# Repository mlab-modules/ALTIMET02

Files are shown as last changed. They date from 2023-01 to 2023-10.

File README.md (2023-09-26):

# ALTIMET02 - Precision Digital Pressure, temperature, and altimeter sensor

The [MLAB ALTIMET02](https://github.com/mlab-modules/ALTIMET02) is a high-performance pressure and temperature sensing module, based on the [MS561101BA03](https://www.te.com/usa-en/product-MS561101BA03-50.html) pressure sensor. This module is designed for use in a variety of applications, including meteorology, navigation, climate monitoring, and other scientific and industrial applications. 

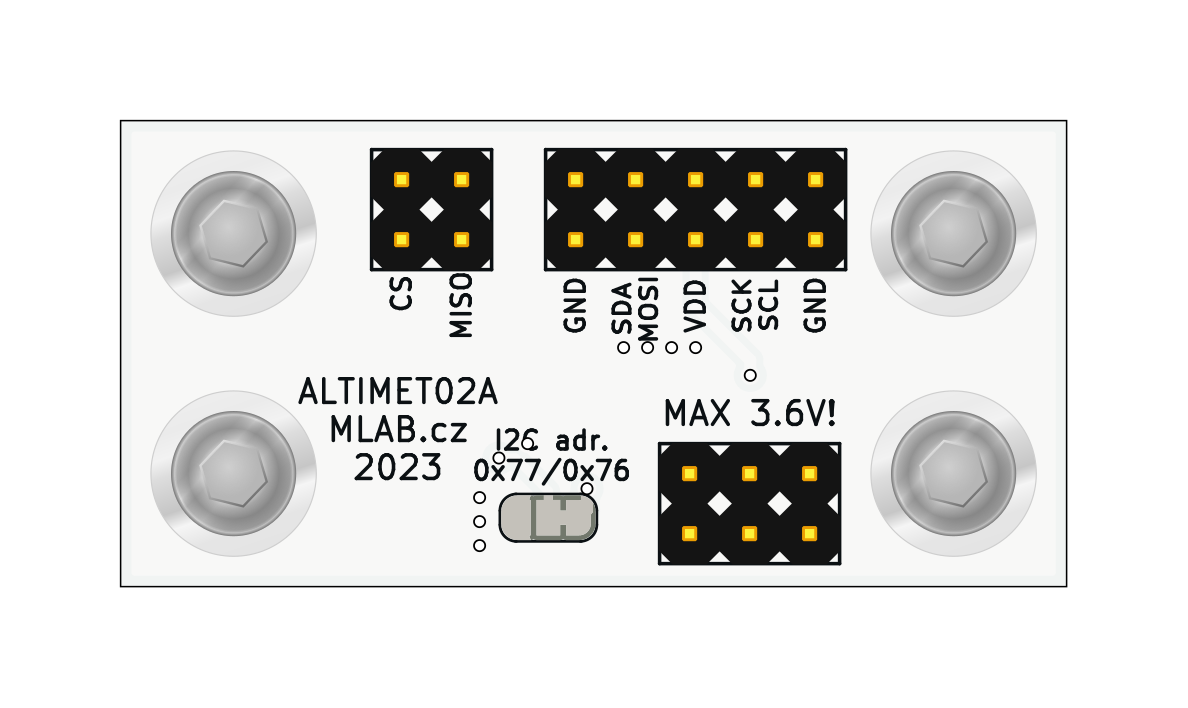
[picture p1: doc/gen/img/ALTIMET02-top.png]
ALTIMET02A top PCB
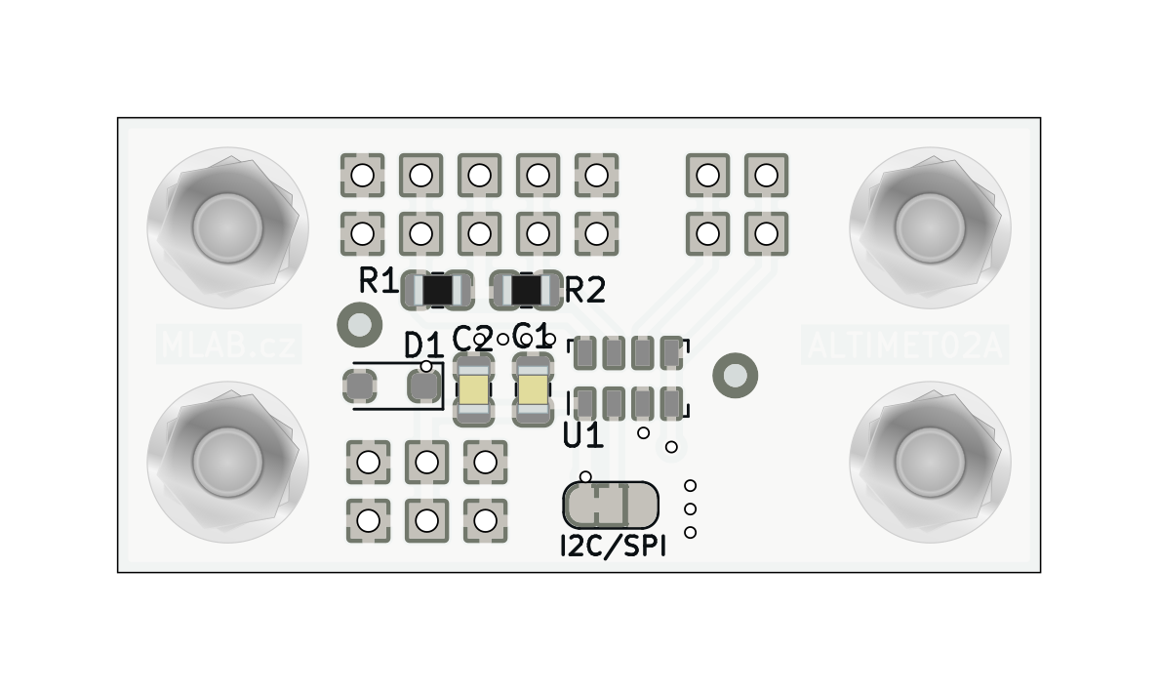
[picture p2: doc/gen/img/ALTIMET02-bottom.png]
ALTIMET02A bottom PCB
 

## Specifications

The key component of the ALTIMET02 module is TE Connectivity MS561101BA03 sensor. This sensor is a highly accurate and low-power barometric sensor with a resolution of up to 10 cm. The sensor provides a 24-bit digital output via the I2C or SPI interfaces, allowing for easy integration with various microcontrollers.

ALTIMET02 Module Schematic

### Parameters

* Pressure and Temperature measurement
* Pressure resolution: 10 cm
* Temperature resolution: 0.01°C
* Communication interface: I2C and SPI
* Supply voltage: 1.8V to 3.6V
* Power consumption: Low (<1uA during measurement)
* Full-scale pressure range: 10 - 1200 mbar
* Operating temperature range: -40 to +85 °C
* High reliability and long-term stability
* Advanced error compensation
* Enhanced EMI Protection

## Use Cases

The ALTIMET02 module is primarily designed as a pressure-sensing device for scientific experiments like statospheric balloons, but its capabilities extend far beyond this purpose. With high accuracy and low power consumption, the module is ideal for a wide range of applications.

### Atmospheric pressure and meteorological applications

As an atmospheric pressure sensor, ALTIMET02 is extremely suitable for meteorological applications. The module can be used for tracking pressure changes over time, which can provide valuable data for weather prediction. The combination of pressure and temperature measurements can help create a more detailed picture of atmospheric conditions.

### Altimetry and navigation

Altitude measurement is another key area where ALTIMET02 excels. Altitude measurement can be done using the barometric method, which uses the change in atmospheric pressure with altitude. This is useful for various types of navigation, including hiking, aviation, and marine navigation.

### Climate monitoring and scientific applications

ALTIMET02 is also a tool for scientific and industrial applications where it is important to monitor changes in climatic conditions. The module can be, for example, used in the field of scientific research to study climate change or in industry for monitoring and controlling conditions in various environments, such as greenhouses, warehouses, and production halls.

### Low power consumption applications

Due to its low power consumption, ALTIMET02 is suitable for applications that require long-term monitoring without frequent charging or battery replacement. This can include remote weather stations, animal trackers, or other portable devices.

## Connection to Microcontroller

The ALTIMET02 module can be easily connected to a microcontroller via the I2C or SPI interfaces.

For connecting the module to a microcontroller via the I2C interface, it is necessary to connect SDA (data line) and SCL (clock line) to the corresponding pins on the microcontroller.

For connection via the SPI interface, it is necessary to connect CSB (chip select), SDO (serial data output), SDI (serial data input), and SCLK (serial clock) to the corresponding pins on the microcontroller.

## Conclusion

The ALTIMET02 module is a highly accurate and low-power pressure and temperature

 sensing module, ideal for various applications. Its simple interface and small size allow for easy integration into any project. Its wide range of uses makes it an ideal solution for many different applications. For further information, please refer to the [ALTIMET02](https://github.com/mlab-modules/ALTIMET02) and the [MLAB website](https://www.mlab.cz/).

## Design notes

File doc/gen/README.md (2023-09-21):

# PCB

Board size: 40.13x19.81 mm (1.58x0.78 inches)

- This is the size of the rectangle that contains the board
- Thickness: 1.6 mm (63 mils)
- Material: FR4
- Finish: None
- Layers: 2
- Copper thickness: 35 µm

Solder mask: TOP / BOTTOM

- Color: Green

Silk screen: TOP / BOTTOM

- Color: White

Stackup:

| Name | Type | Color | Thickness | Material | Epsilon_r | Loss tangent |
|---|---|---|---|---|---|---|
| F.SilkS | Top Silk Screen | | | | | |
| F.Paste | Top Solder Paste | | | | | |
| F.Mask | Top Solder Mask | | 10 | | | |
| F.Cu | copper | | 35 | | | |
| dielectric 1 | core | | 1510 | FR4 | 4.5 | 0.020 |
| B.Cu | copper | | 35 | | | |
| B.Mask | Bottom Solder Mask | | 10 | | | |
| B.Paste | Bottom Solder Paste  | | | | | |
| B.SilkS | Bottom Silk Screen | | | | | |

# Important sizes

Clearance: 0.2 mm (8 mils)

Track width: 0.25 mm (10 mils)

- By design rules: 0.0 mm (0 mils)

Drill: 0.5 mm (20 mils)

- Vias: 0.5 mm (20 mils) [Design: 0.4 mm (16 mils)]
- Pads: 1.0 mm (39 mils)
- The above values are real drill sizes, they add 0.1 mm (4 mils) to plated holes (PTH)

Via: 0.8/0.4 mm (31/16 mils)

- By design rules: 0.5/0.3 mm (20/12 mils)
- Micro via: yes [0.2/0.1 mm (8/4 mils)]
- Buried/blind via: yes
- Total: 11 (thru: 11 buried/blind: 0 micro: 0)

Outer Annular Ring: 0.15 mm (6 mils)

- By design rules: 0.26 mm (10 mils)

Eurocircuits class: 4B
- Using min drill 0.5 mm for an OAR of 0.15 mm

# General stats

Components count: (SMD/THT)

- Top: 0/7 (THT)
- Bottom: 8/0 (SMD)

Defined tracks:

Used tracks:

- 0.25 mm (10 mils) (2) defined: no
- 0.38 mm (15 mils) (19) defined: no
- 0.4 mm (16 mils) (10) defined: no
- 0.51 mm (20 mils) (25) defined: no

Defined vias:

Used vias:

- 0.8/0.4 mm (31/16 mils) (Count: 11, Aspect: 2.0 A) defined: no

Holes (excluding vias):

- 0.89 mm (35 mils) (20)
- 3.0 mm (118 mils) (4)

Oval holes:

Drill tools (including vias and computing adjusts and rounding):

- 0.5 mm (20 mils) (11)
- 1.0 mm (39 mils) (20)
- 3.1 mm (122 mils) (4)

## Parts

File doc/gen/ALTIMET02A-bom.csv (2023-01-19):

Row | Description | Part | References | Value | Footprint | Quantity Per PCB | Status | Datasheet | Height | Mouser Part Number | Mouser Price/Stock | Manufacturer_Name | Manufacturer_Part_Number
1 | Unpolarized capacitor | C | C2 | 100nF | C_0805_2012Metric | 1 |  | ~
2 | Unpolarized capacitor | C | C1 | 10uF | C_0805_2012Metric | 1 |  | ~
3 | Zener diode | D_Zener | D1 | BZV55C3V6 | Diode-MiniMELF_Standard | 1 |  | ~
4 | Sensor Pressure 1.2bar Barometric SMD MS561101BA03-50, Barometric Pressure Sensor, 1200mbar 0 3.6 V Output, 8-Pin QFN | MS561101BA03-50 | IC1 | MS561101BA03-50 | MS561101BA03-50 | 1 |  | https://www.te.com/usa-en/product-MS561101BA03-50.datasheet.pdf |  | 824-MS561101BA03-50 | https://www.mouser.co.uk/ProductDetail/Measurement-Specialties/MS561101BA03-50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 | TE Connectivity | MS561101BA03-50
5 | 2x03 2.54 mm pitch header | HEADER_2x03 | J2 | HEADER_2x03 | Straight_2x03 | 1
6 | 2x05 2.54 mm pitch header, 2 pins next to each other are connected | HEADER_2x05_PARALLEL | J3 | HEADER_2x05_PARALLEL | Straight_2x05 | 1
Project info:
Schematic: | ALTIMET02A
Variant: | default
Revision: | A
Date: | 2023-01-18
KiCad Version: | 6.0.10+dfsg-1~bpo11+1
Statistics:
Component Groups: | 7
Component Count: | 8
Fitted Components: | 6
Number of PCBs: | 1
Total Components: | 6

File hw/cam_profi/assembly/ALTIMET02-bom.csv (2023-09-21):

Component | Description | Part | References | Value | Footprint | Quantity Per PCB | Datasheet | ust_id
1 | Unpolarized capacitor | C | C2 | 100nF | C_0805_2012Metric | 1 | ~ | 5c70984712875079b91f8b4c
2 | Unpolarized capacitor | C | C1 | 10uF | C_0805_2012Metric | 1 | ~ | 5c70984712875079b91f8b53
3 | Zener diode | D_Zener | D1 | BZT52H-C3V6,115 | D_SOD-123F | 1 | ~ | 650b35ab462c6d9e720543d0
4 | 2x02 2.54 mm pitch header, 2 pins next to each other are connected | HEADER_2x02_PARALLEL | J1 | HEADER_2x02_PARALLEL | Straight_2x02 | 1
5 | 2x03 2.54 mm pitch header, 2 pins next to each other are connected | HEADER_2x03_PARALLEL | J2 | HEADER_2x03_PARALLEL | Straight_2x03 | 1
6 | 2x05 2.54 mm pitch header, 2 pins next to each other are connected | HEADER_2x05_PARALLEL | J3 | HEADER_2x05_PARALLEL | Straight_2x05 | 1
7 | Resistor | R | R1R2 | 5k1 | R_0805_2012Metric | 2 | ~ | 5fa0fc3e12875025b3977997
8 | Barometric pressure sensor, 10cm resolution, 10 to 1200 mbar, I2C and SPI interface up to 20MHz, LGA-8 | MS5611-01BA | U1 | MS5611-01BA | MS5611-01BA03 | 1 | https://www.te.com/commerce/DocumentDelivery/DDEController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 | 650b36b0462c6d9e720543f4

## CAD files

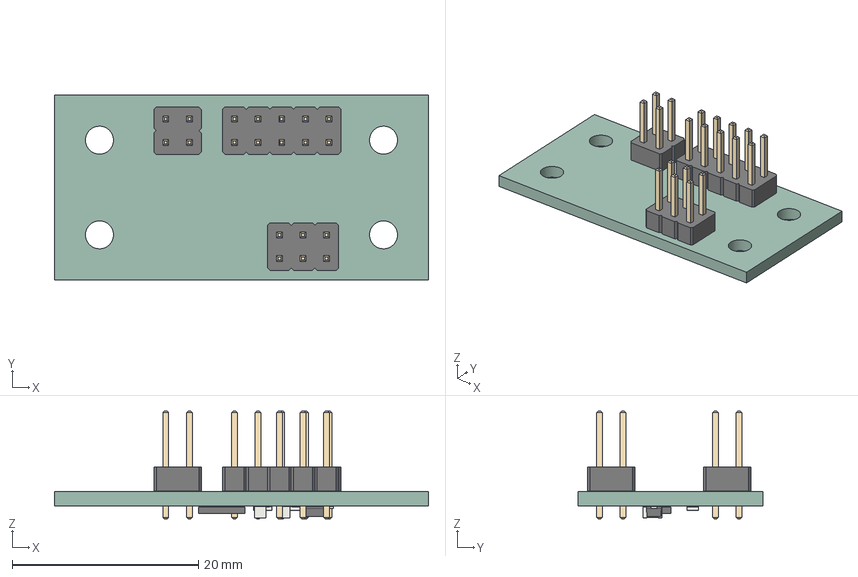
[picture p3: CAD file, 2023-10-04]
doc/gen/ALTIMET02.step
40.1 x 19.8 x 11.5 mm
tmp0cc4rao0 PCB

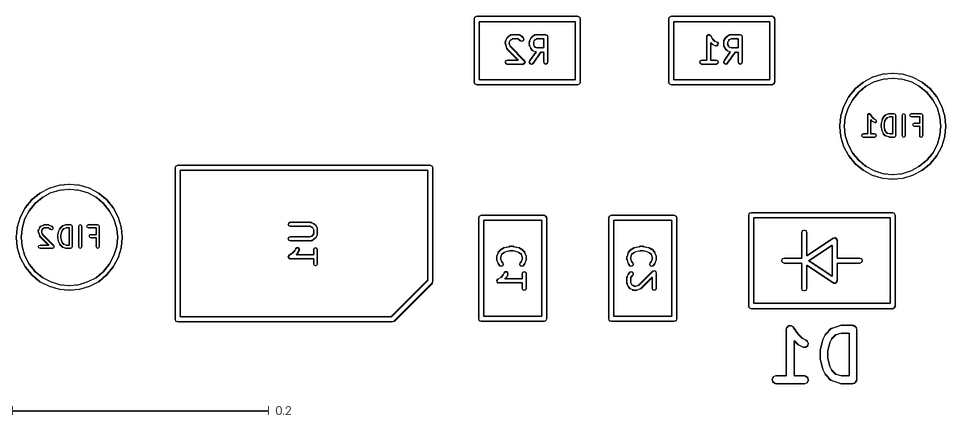
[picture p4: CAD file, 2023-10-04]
doc/gen/dxf/ALTIMET02-B_Fab.dxf
0.724 x 0.286

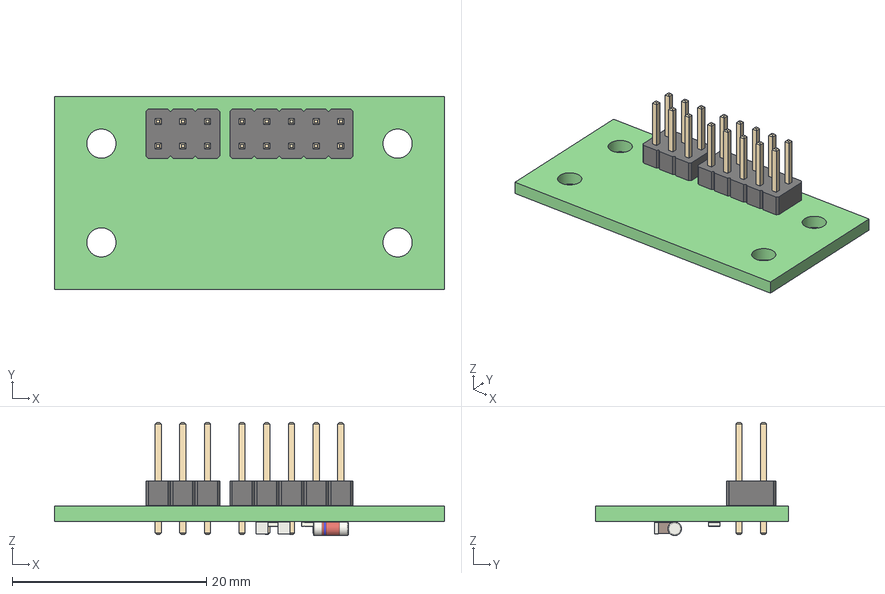
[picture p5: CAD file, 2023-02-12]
doc/gen/ALTIMET02A.step
40.1 x 19.8 x 11.6 mm
tmpe_0kkv2t PCB

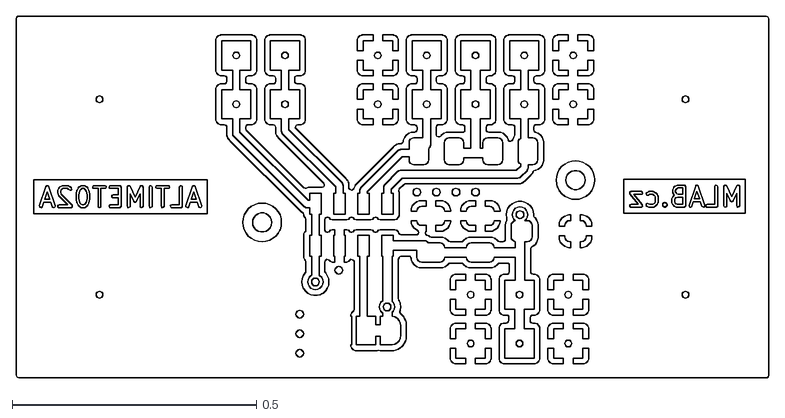
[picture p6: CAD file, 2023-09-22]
doc/gen/dxf/ALTIMET02-B_Cu.dxf
1.54 x 0.741

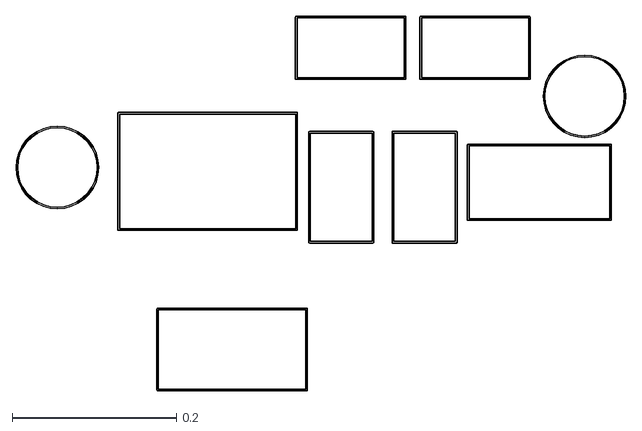
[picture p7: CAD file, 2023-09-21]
doc/gen/dxf/ALTIMET02-B_Courtyard.dxf
0.742 x 0.456

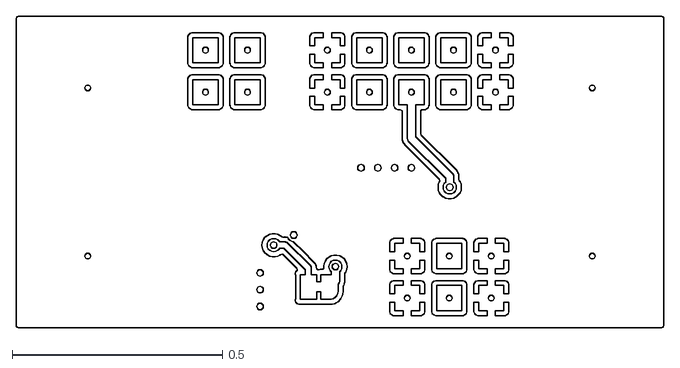
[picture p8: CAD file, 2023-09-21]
doc/gen/dxf/ALTIMET02-F_Cu.dxf
1.54 x 0.741

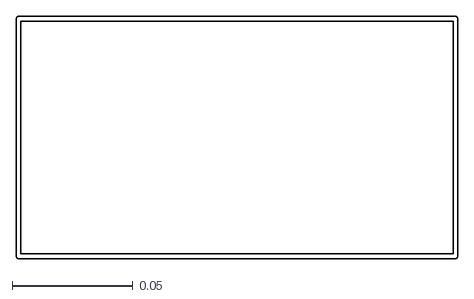
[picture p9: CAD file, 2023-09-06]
doc/gen/dxf/ALTIMET02-F_Courtyard.dxf
0.183 x 0.1

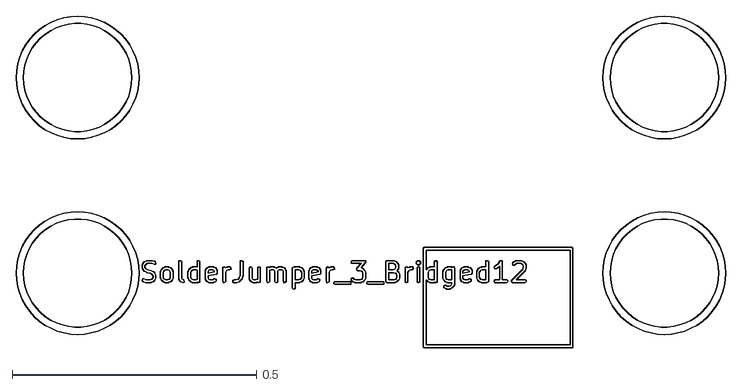
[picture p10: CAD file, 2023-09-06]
doc/gen/dxf/ALTIMET02-F_Fab.dxf
1.45 x 0.679

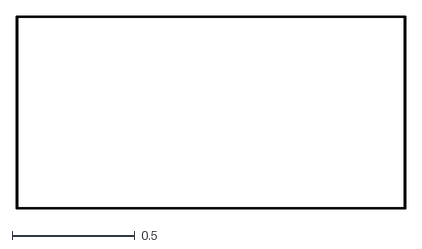
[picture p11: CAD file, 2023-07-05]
doc/gen/dxf/ALTIMET02-Edge_Cuts.dxf
1.58 x 0.785

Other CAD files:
doc/gen/dxf/ALTIMET02-User_Comments.dxf
doc/gen/dxf/ALTIMET02-User_2.dxf
doc/gen/dxf/ALTIMET02A-User_9.dxf
doc/gen/dxf/ALTIMET02A-User_3.dxf
doc/gen/dxf/ALTIMET02-User_6.dxf
doc/gen/dxf/ALTIMET02-Margin.dxf
doc/gen/dxf/ALTIMET02A-User_Drawings.dxf
doc/gen/dxf/ALTIMET02-User_8.dxf
doc/gen/dxf/ALTIMET02A-User_2.dxf
doc/gen/dxf/ALTIMET02-B_Adhesive.dxf
doc/gen/dxf/ALTIMET02-B_Mask.dxf
doc/gen/dxf/ALTIMET02-B_Paste.dxf
doc/gen/dxf/ALTIMET02-B_Silkscreen.dxf
doc/gen/dxf/ALTIMET02-F_Adhesive.dxf
doc/gen/dxf/ALTIMET02-F_Mask.dxf
doc/gen/dxf/ALTIMET02-F_Paste.dxf
doc/gen/dxf/ALTIMET02-F_Silkscreen.dxf
doc/gen/dxf/ALTIMET02-User_1.dxf
doc/gen/dxf/ALTIMET02-User_3.dxf
doc/gen/dxf/ALTIMET02-User_4.dxf
doc/gen/dxf/ALTIMET02-User_5.dxf
doc/gen/dxf/ALTIMET02-User_7.dxf
doc/gen/dxf/ALTIMET02-User_9.dxf
doc/gen/dxf/ALTIMET02-User_Drawings.dxf
doc/gen/dxf/ALTIMET02-User_Eco1.dxf
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

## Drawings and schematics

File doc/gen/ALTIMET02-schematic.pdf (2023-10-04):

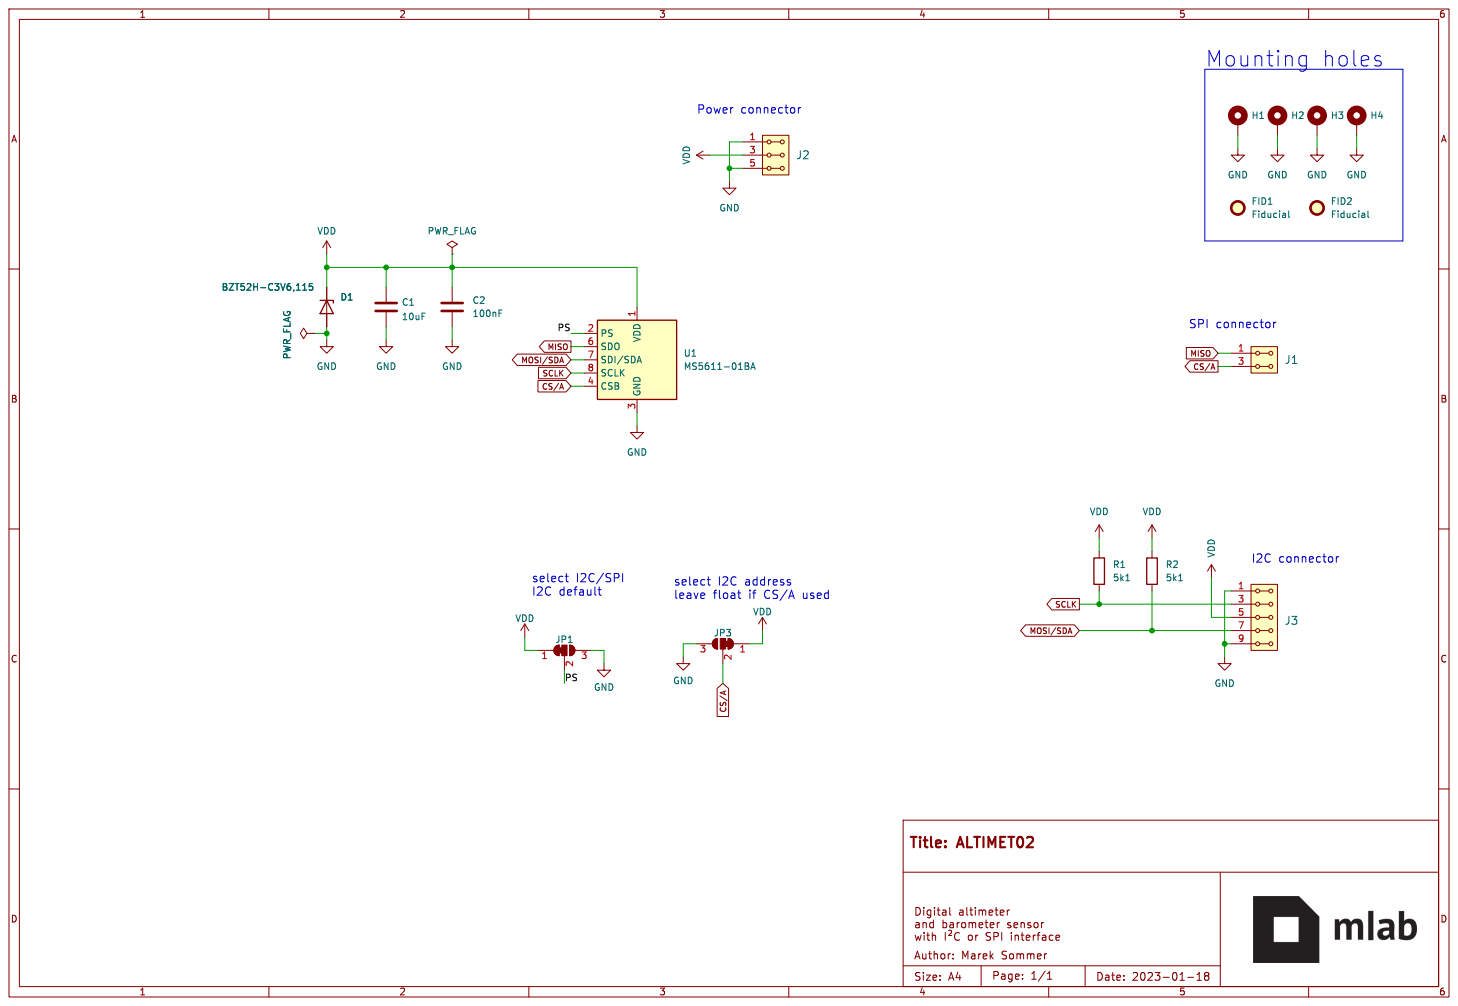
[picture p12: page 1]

3 CSB 4 SDO 6 SDI/SDA 7 SCLK 8 U1 MS5611-01BA GND

leave float if CS/A used

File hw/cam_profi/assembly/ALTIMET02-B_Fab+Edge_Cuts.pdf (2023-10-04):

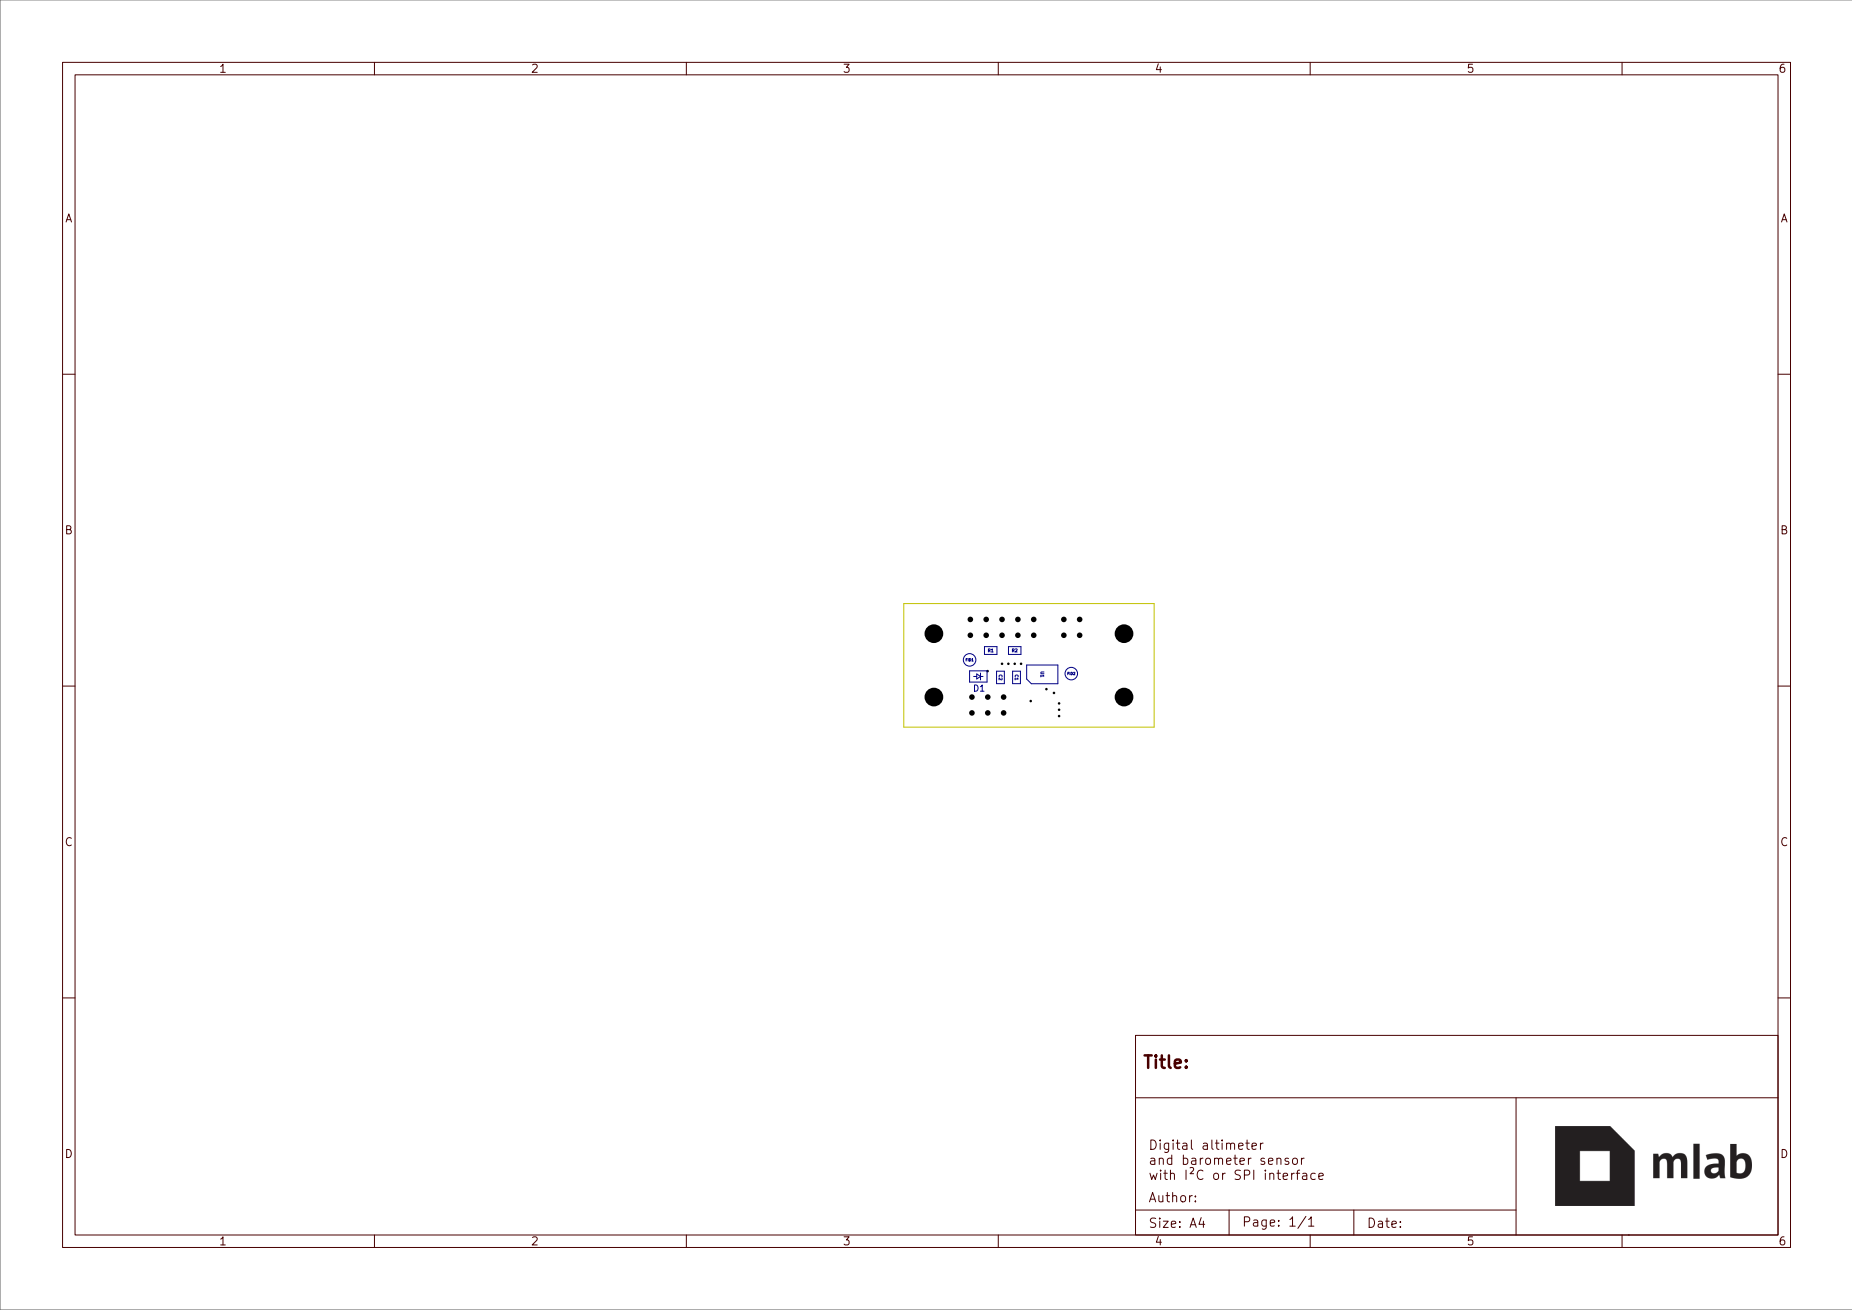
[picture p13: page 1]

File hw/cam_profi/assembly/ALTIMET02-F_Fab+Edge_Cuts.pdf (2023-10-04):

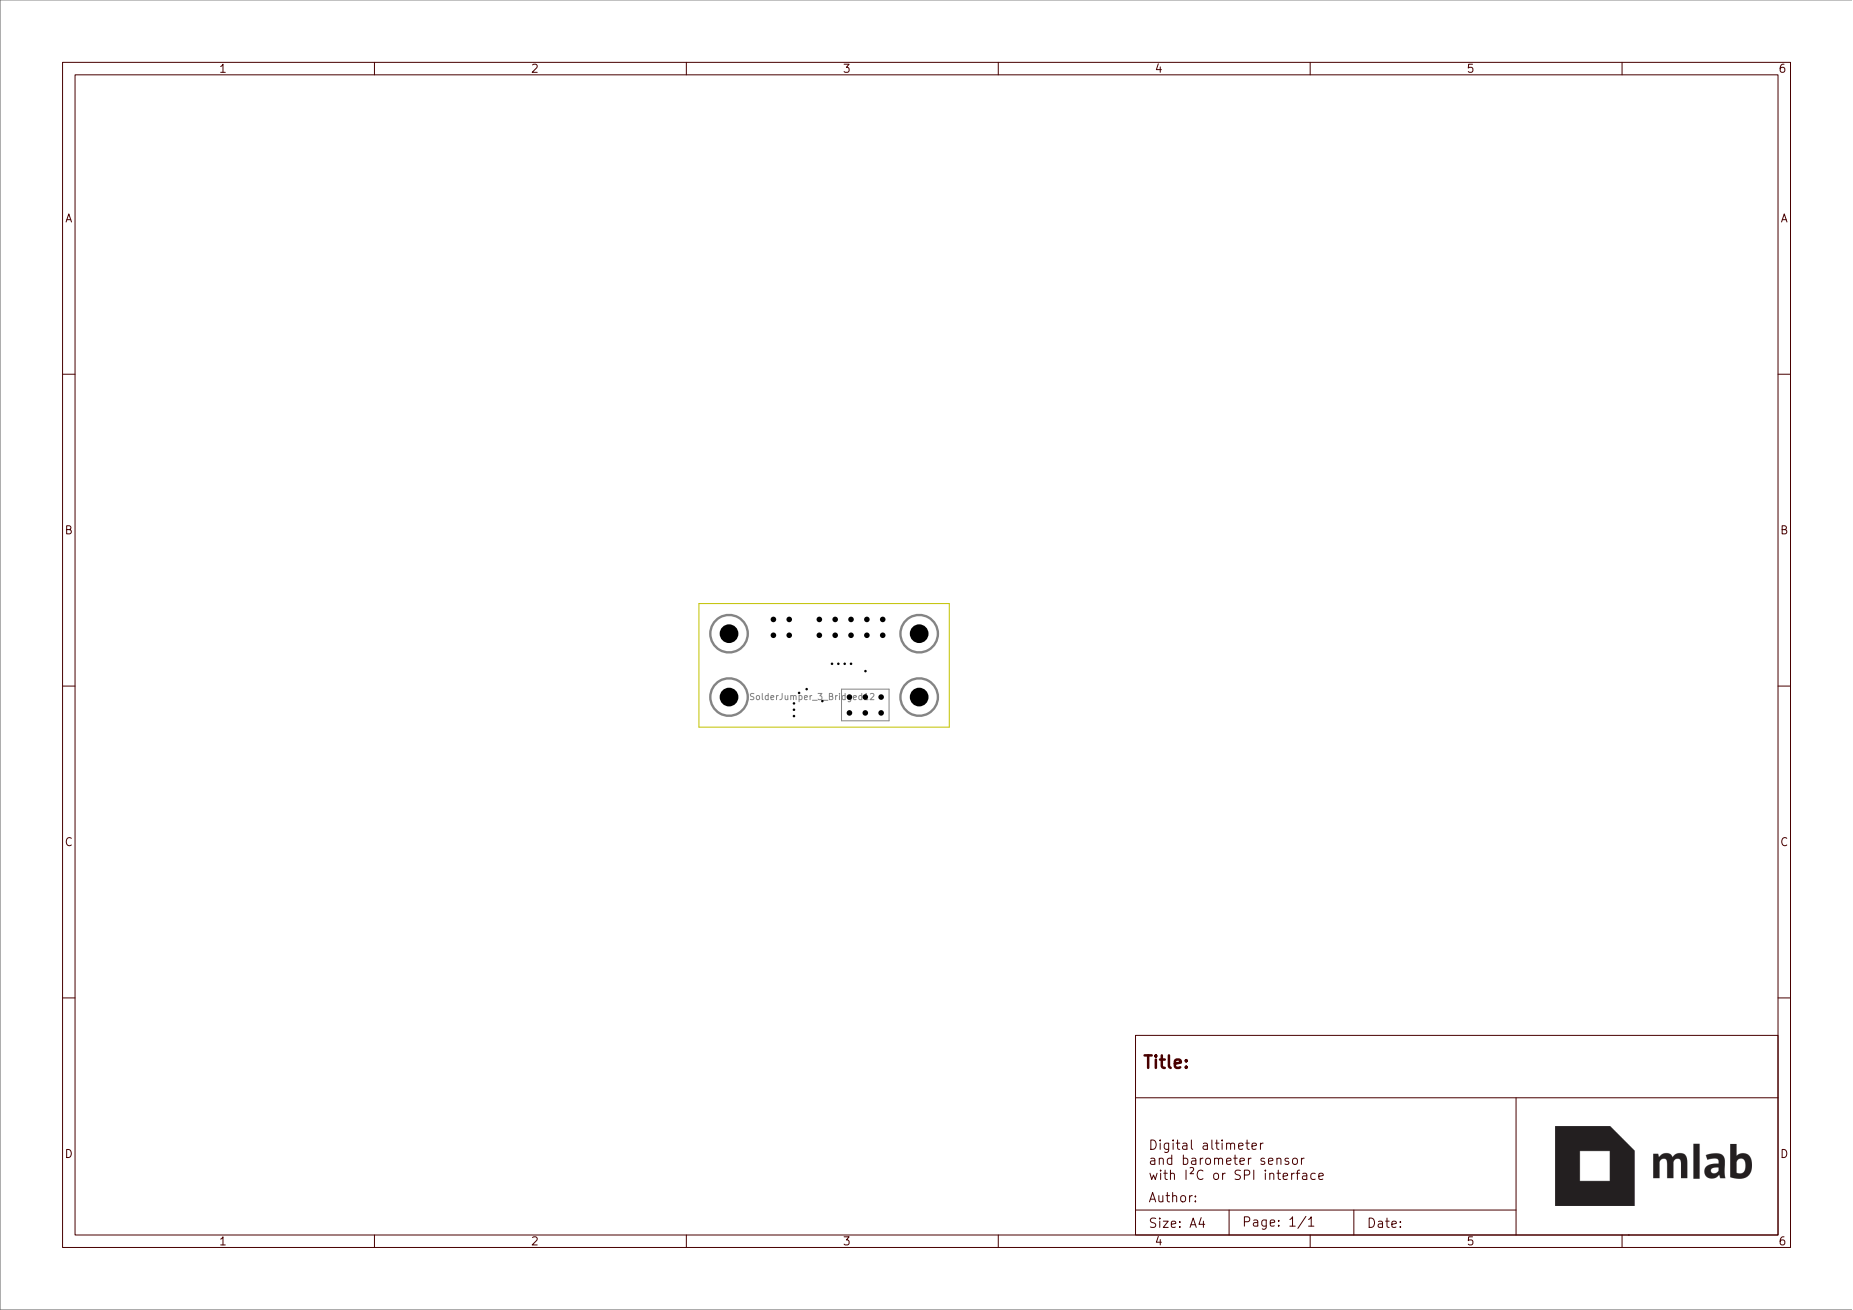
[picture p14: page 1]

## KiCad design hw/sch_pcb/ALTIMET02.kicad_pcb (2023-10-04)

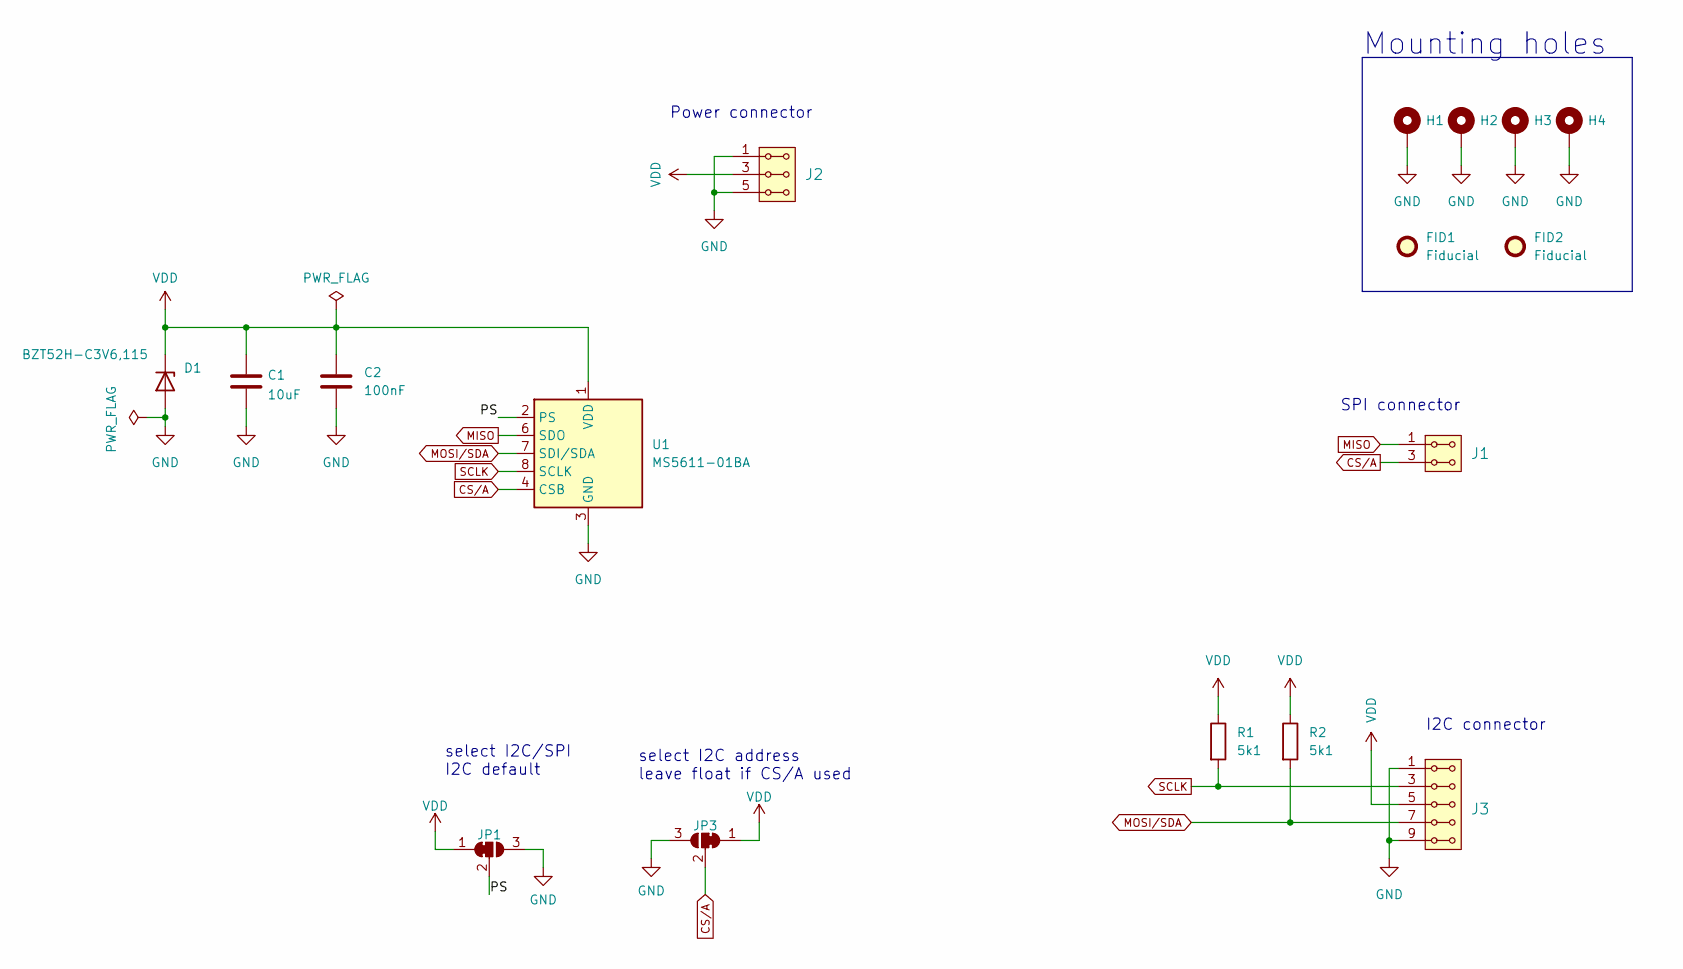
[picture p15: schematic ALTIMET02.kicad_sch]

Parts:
C1: 10uF; C_0805_2012Metric
C2: 100nF; C_0805_2012Metric
D1: BZT52H-C3V6,115; D_SOD-123F
FID1, FID2: Fiducial; Fiducial_1mm_Mask2mm
H1, H2, H3, H4: MountingHole_Pad; MountingHole_3mm
J1: HEADER_2x02_PARALLEL; Straight_2x02
J2: HEADER_2x03_PARALLEL; Straight_2x03
J3: HEADER_2x05_PARALLEL; Straight_2x05
JP1, JP3: SolderJumper_3_Bridged12; SolderJumper-3_P1.3mm_Bridged12_RoundedPad1.0x1.5mm_NumberL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
R1, R2: 5k1; R_0805_2012Metric
U1: MS5611-01BA; MS5611-01BA03

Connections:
/PS: JP1.2 (C), U1.2 (PS)
CS/A: J1.3, J1.4, JP3.2 (C), U1.4 (CSB), U1.5 (CSB)
GND: C1.2, C2.2, D1.2 (A), H1.1, H2.1, H3.1, H4.1, J2.1, J2.2, J2.5, J2.6, J3.1, J3.2, J3.9, J3.10, JP1.3 (B), JP3.3 (B), U1.3 (GND)
MISO: J1.1, J1.2, U1.6 (SDO)
MOSI/SDA: J3.7, J3.8, R2.2, U1.7 (SDI/SDA)
SCLK: J3.3, J3.4, R1.2, U1.8 (SCLK)
VDD: C1.1, C2.1, D1.1 (K), J2.3, J2.4, J3.5, J3.6, JP1.1 (A), JP3.1 (A), R1.1, R2.1, U1.1 (VDD)

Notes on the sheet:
select I2C/SPI I2C default
Mounting holes
SPI connector
Power connector
select I2C address leave float if CS/A used
I2C connector

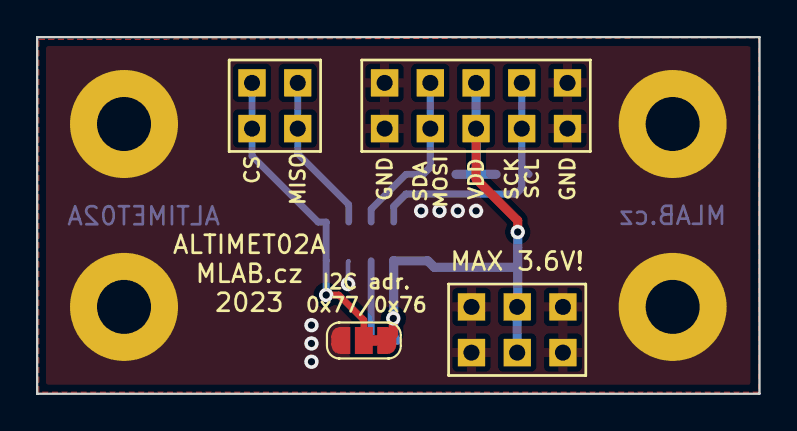
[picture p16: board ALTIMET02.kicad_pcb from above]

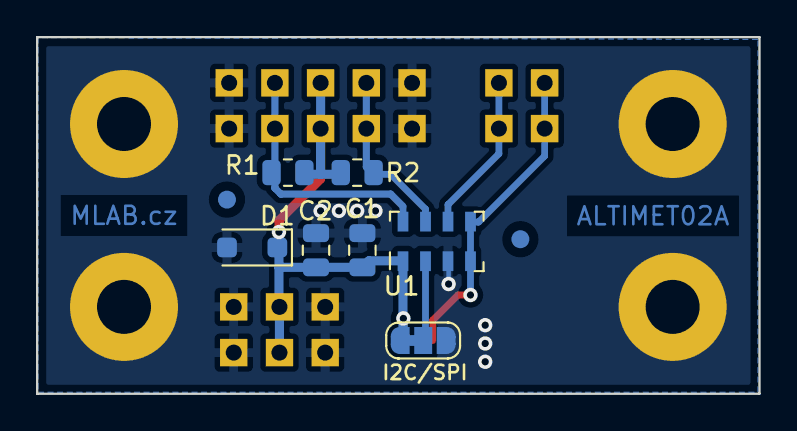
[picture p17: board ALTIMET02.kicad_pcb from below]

Board: 2 copper layers, 40.1 x 19.8 mm, 17 parts (9 on the bottom side), 7 nets.

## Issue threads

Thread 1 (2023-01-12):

I2C pull-up add

ChroustJan, 2023-01-12:

roman-dvorak, 2023-08-21:
Tady se defaultně počítá se SPI nastavením, nebo proč jsou pullupy označeny jako DNF? Škrábací/pájecí propojka je ve výchozím stavu nastavena právě jako I2C.

PS: KiCAD7 umožňuje nastavit součástce hodnotu a pak ji označit jako DNF. Ve schématu se to projeví jejím škrtnutím
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

Významem toho je, že tato informace se snáze propíše do návazných systémů a někde je následně skrytá.

Closed 2023-01-16.

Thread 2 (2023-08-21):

Zdvojení SPI pinů

roman-dvorak, 2023-08-21:
Nelíbí se mi, že v návrhu jsou některé SPI piny vyvedeny pouze jednou.

Některé piny jsou využity jak pro SPI tak i I2C rozhraní. Tento stav není reflektován na silkscreenu:
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

Navrhuji to vyřešit tak, že u pinů, které už jsou vyvedeny do I2C konektoru, bude popsán i jejich SPI význam. Na druhý konektor budou vyvedeny SPI piny které nejsou v I2C konektoru. Tyto piny budou standartně zdvojeny.

Jedná se tedy o MISO, CS/A, MOSI

Standartní napájecí konektor tam není z důvodu místa?

Trošku riskantní mi připadá situace, kdy existuje hřebínek s popiskem CS, který je ve výchozí stavu připojen do GND.
To by zřejmě šlo vyřešit tak, že CSB pin bude připojen k velkému pull-up rezistoru. To bude stačit k tomu, aby běžně byla nastavena I2C adresa na 1. Pokud odpor bude dostatečně velký, tak by nemusel vadit při používání SPI.

Alternativní řešení je, mezi JP3 a CS/A větev dát odpor do série.

Sommema4, 2023-08-25:
Jak už jsem psal Kubovi do https://github.com/mlab-modules/FRAM01/issues/1. Měl jsem za to, že jsem tohle rozležení SPI konektoru obšlehnul z nějakých MLAB desek. Proto ho používám a proto nejsou zdvojený SPI piny.

Standardní napájecí konektor mi bylo řečeno, že není potřeba (předchozí facebooková dohoda).

Primární určení je pro použití s I2C (tak mi to bylo řečeno). Proto je default nastavení I2C, tj. CS/A je "jenom" výběr adresy. Nicméně asi máš pravdu, že by bylo bezpečnější, kdyby to nevedlo na zem. Připadá mi ale výrazně jednodušší hodit akorát CS/A pin na napájení a tím se akorát změní I2C adresa. Nicméně o tomhle už se vedla poměrně dlouhá diskuze a už jsme se na tom podle mě jednou dohodli.

roman-dvorak, 2023-09-20:
Vyřešeno:

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

Closed 2023-09-20.

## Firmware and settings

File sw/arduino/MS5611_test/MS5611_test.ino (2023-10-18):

//
//    FILE: MS5611_test_plotter.ino
//  AUTHOR: Rob Tillaart
// PURPOSE: demo application
//    DATE: 2022-01-15
//     URL: https://github.com/RobTillaart/MS5611


#include "MS5611.h"

MS5611 MS5611(0x76);

void setup()
{
  Serial.begin(115200);
  while (!Serial);

  pinMode(LED_BUILTIN, OUTPUT);

  Serial.println();
  if (MS5611.begin() == true)
  {
    Serial.println("MS5611 found.");
  }
  else
  {
    Serial.println("MS5611 not found. halt.");
    while (1)
    {
      digitalWrite(LED_BUILTIN, HIGH);
      delay(1000);
      digitalWrite(LED_BUILTIN, LOW);
      delay(1000);
    }
  }
  Serial.println("TEMP\tPRESSURE");

  MS5611.setOversampling(OSR_ULTRA_HIGH);

}

void loop()
{
  digitalWrite(LED_BUILTIN, HIGH);
  MS5611.read();
  Serial.print(MS5611.getTemperature(), 4);
  Serial.print("\t");
  Serial.print(MS5611.getPressure(), 4);
  Serial.println();
  digitalWrite(LED_BUILTIN, LOW);
  delay(50);
}

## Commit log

2023-01-12 Add files via upload
    KiCAD schematics
    [ALTIMET02A.kicad_pcb, ALTIMET02A.kicad_sch]
2023-01-12 Edit schema.
    [ALTIMET02A.kicad_sch]
2023-01-16 pcb layout
    [ALTIMET02A.kicad_pcb, ALTIMET02A.kicad_sch]
2023-01-16 DNF values added
    [ALTIMET02A.kicad_sch]
2023-01-17 3x1 layout
    [ALTIMET02A.kicad_pcb, ALTIMET02A.kicad_sch]
2023-01-18 Change directory structure.
    [ALTIMET02A.kicad_pcb, ALTIMET02A.kicad_sch]
2023-01-18 Fix title block.
    [ALTIMET02A.kicad_sch]
2023-01-18 Update actions products
    [ALTIMET02A-B_Adhesive.dxf, ALTIMET02A-B_Courtyard.dxf, ALTIMET02A-B_Cu.dxf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]
2023-01-18 Explicit name of kicad project files.
2023-01-18 Add pwr_flags to resolve ERC issues.
    [ALTIMET02A.kicad_sch]
2023-01-18 Fix duplicate PWR_Flag Update symbols from libraries.
    [ALTIMET02A.kicad_sch]
2023-01-19 GND via added
    [ALTIMET02A.kicad_pcb]
2023-01-19 Layout and silkscreen improvements.
    [ALTIMET02A.kicad_pcb]
2023-01-19 power header deleted, i2c/spi solder jumper moved to the back side, i2c addr. added
    [ALTIMET02A.kicad_pcb, ALTIMET02A.kicad_sch]
2023-01-20 Improve layout and silkscreen.
    [ALTIMET02A.kicad_pcb]
2023-02-12 Update submodule Fix CLK in silkscreen.
    [ALTIMET02A.kicad_pcb]
2023-02-12 Update worflow rename KiCAD project.
    [ALTIMET02.kicad_pcb, ALTIMET02.kicad_sch]
2023-09-06 power connector added, SPI and I2C connectors modified, default I2C adrress changed
    [ALTIMET02.kicad_pcb, ALTIMET02.kicad_sch]
2023-09-06 minor changes in layout, change diode
    [ALTIMET02.kicad_pcb, ALTIMET02.kicad_sch]
2023-09-06 add fiducial
    [ALTIMET02.kicad_pcb, ALTIMET02.kicad_sch]
2023-09-07 Fix sharp trace. Improve silkscreen.
    [ALTIMET02.kicad_pcb, ALTIMET02.kicad_sch]
2023-09-20 add ustid
    [ALTIMET02.kicad_pcb, ALTIMET02.kicad_sch]
2023-09-21 Upravy a kontrola pred vyrobou
    [ALTIMET02.kicad_pcb, ALTIMET02.kicad_sch]
2023-09-22 Uprava PCB a kontrola UST_ID
    [ALTIMET02.kicad_pcb]
2023-10-04 Edit B.Fab
    [ALTIMET02.kicad_pcb]
